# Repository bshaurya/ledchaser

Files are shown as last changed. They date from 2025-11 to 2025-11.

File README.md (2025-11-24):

# shauryachaser LED Chaser

a cricket-ball themed LED chaser because why not  
hardware-only, no firmware needed. Powered by a 555 + CD4017  
and mounted inside a shiny 3D-printed cricket ball enclosure

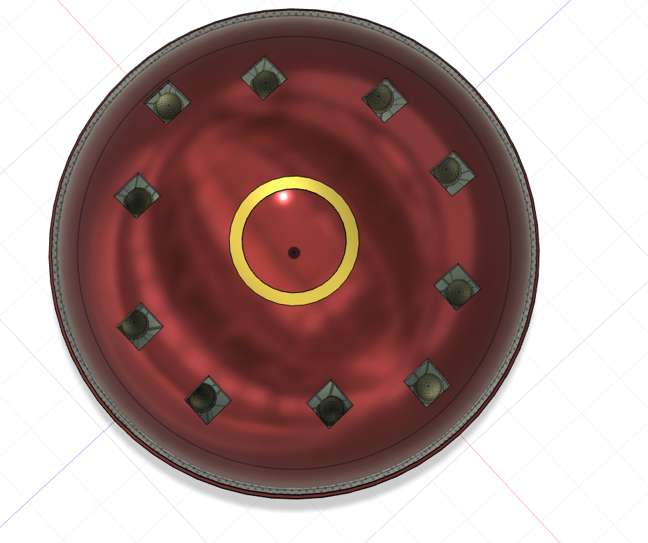
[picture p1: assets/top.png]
Top

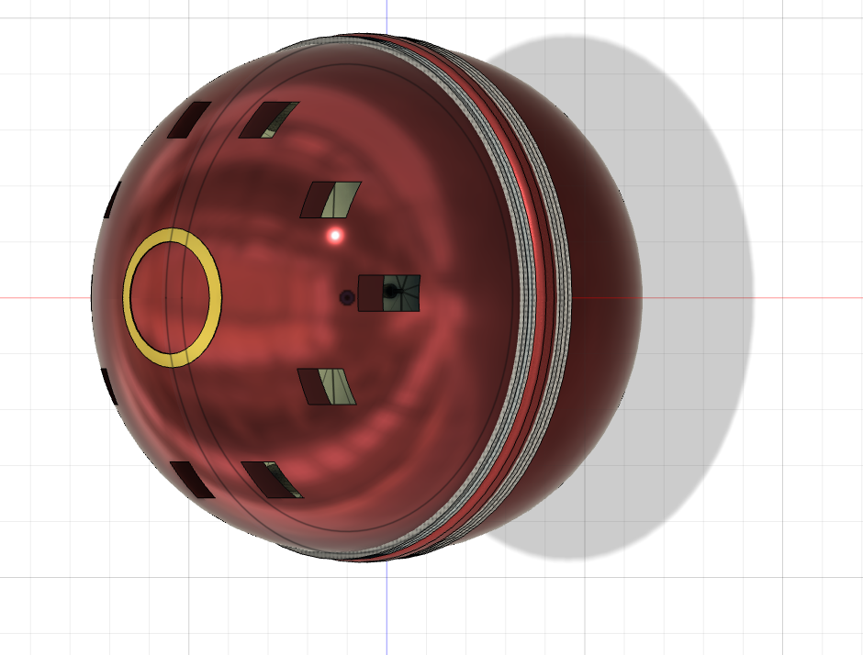
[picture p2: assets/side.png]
Side

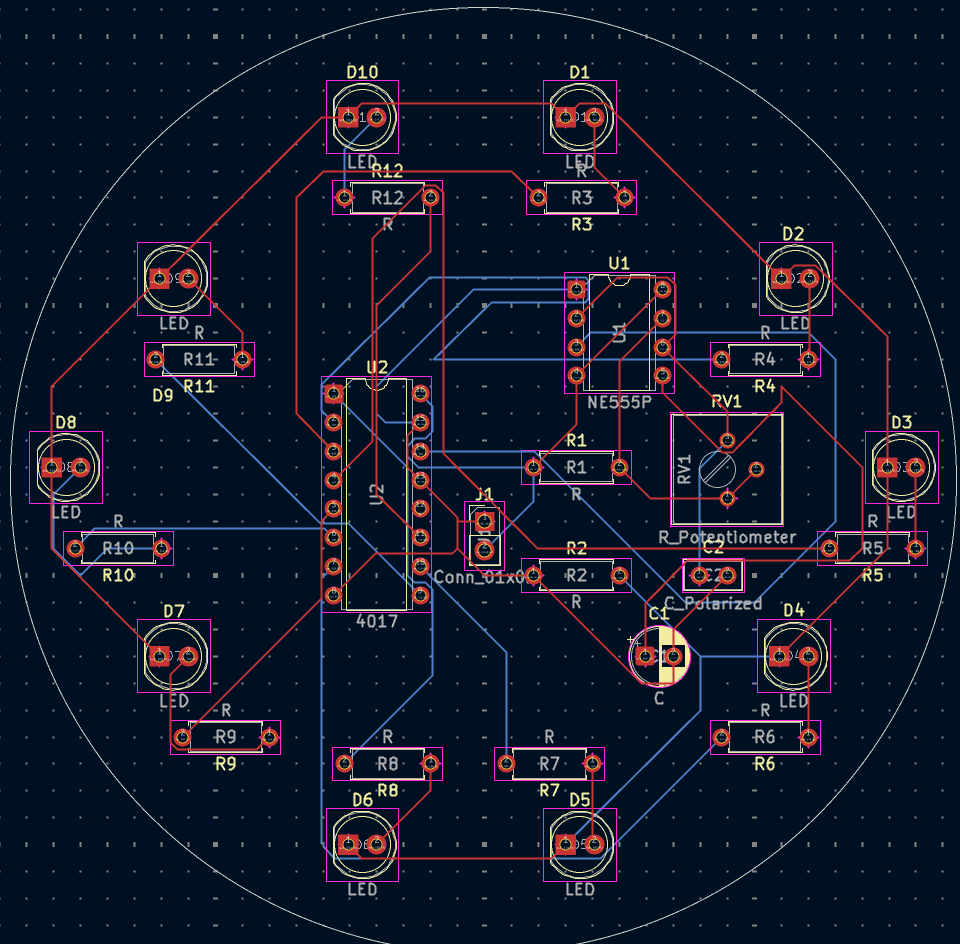
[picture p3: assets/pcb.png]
PCB

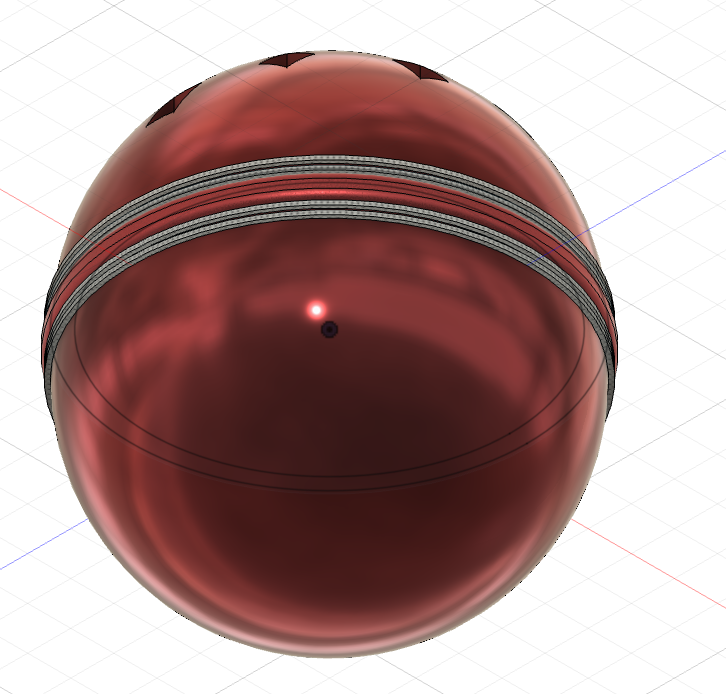
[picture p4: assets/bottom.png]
Bottom

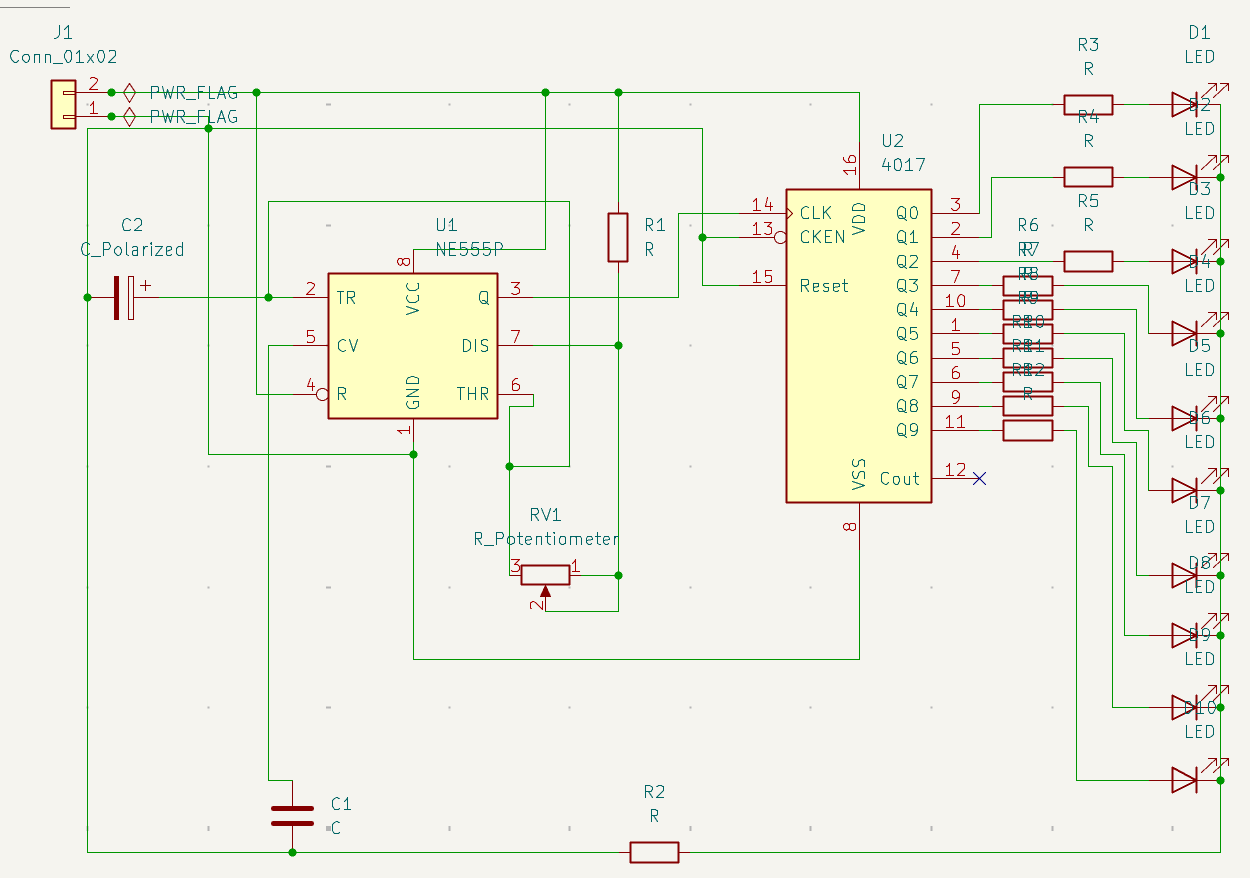
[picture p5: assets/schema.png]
Schematic


## What is this

Basically I wanted to make something fun, weird, and actually functional.  
So I built an LED chaser circuit (classic 555 + CD4017) and wrapped it inside  
a custom Fusion 360 modeled cricket ball enclosure with seam lines, stitching, and a full LED ring.

## Hardware

- **Logic**: NE555P (clock) + CD4017BE (decade counter)
- **LEDs**: 10x 5mm diffused LEDs arranged around the ball
- **Resistors**: 10x LED current limiters + timing resistors
- **Potentiometer**: 50k trim pot for speed control
- **Caps**: 1uF electrolytic + 0.01uF ceramic
- **Power**: Standard 5V input (2-pin header)
- **Enclosure**: 93mm diameter 3D-printed cricket ball with stitched seam

## How it works

- The **555 timer** generates a square wave clock (rate set by RV1).
- Every clock pulse goes into the **CD4017**, which advances to the next output: Q0 → Q1 → Q2 → ... → Q9 → loops back
- Each Q output drives an LED through a 470Ω resistor.
- Result = lights chase around the seam like a rotating/bouncing cricket ball.

You rotate RV1 to speed up or slow down the chase.

## BOM

**ICs**
- 1x NE555P (DIP-8)
- 1x CD4017BE (DIP-16)

**LEDs**
- 10x 5mm LEDs (any color)

**Resistors**
- 10x 470Ω (LEDs)
- 2x 1kΩ (timing)

**Potentiometer**
- 1x 50kΩ trim pot (3386P style)

**Capacitors**
- 1x 1uF electrolytic
- 1x 0.01uF ceramic

**Connectors**
- 1x 2-pin 2.54mm power header

**PCB**
- 1x Circular 93mm custom PCB (KiCad)

**Case**
- ~70–100g PLA (for the cricket ball halves)
- 4x M3x16 screws (optional if mounting)
- 4x M3 heatset inserts (optional)

## Estimated Prices

(approx retail), see BOM.csv

- LEDs: ~$1.00 for all 10  
- Resistors: ~$0.60  
- NE555P: ~$0.40  
- CD4017BE: ~$0.70  
- Potentiometer: ~$0.50  
- Capacitors: ~$0.25  
- Header: ~$0.10  
- PCB: ~$15 (JLCPCB)  
- PLA: ~$1 worth  
**Total:** ~**$20** all-in

## Building one

- `/ledcha` — KiCad PCB + schematic
- `/cad` — 3D Fusion 360 files for the cricket enclosure
- `/assets` — top/side/bottom views, schema and pcb
Steps:

1. Export Gerbers → order PCB from JLCPCB/Seeed/etc.
2. 3D print the cricket ball halves.
3. Solder the PCB: ICs, resistors, LEDs, pot, caps.
4. Insert the PCB inside the enclosure.
5. Power with 5V.
6. Rotate the pot to change chase speed.

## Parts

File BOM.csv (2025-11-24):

Designator | Quantity | Value | Description | Package | Estimated Unit Price (USD) | Estimated Total Price (USD)
U1 | 1 | NE555P | 555 Timer DIP-8 | DIP-8_W7.62mm | 0.40 | 0.40
U2 | 1 | CD4017BE | Decade Counter DIP-16 | DIP-16_W7.62mm | 0.70 | 0.70
R1 | 1 | 1kΩ | Resistor 1kΩ | Axial 7.62mm | 0.05 | 0.05
R2 | 1 | 1kΩ | Resistor 1kΩ | Axial 7.62mm | 0.05 | 0.05
R3 | 1 | 470Ω | LED Series Resistor | Axial 7.62mm | 0.05 | 0.05
R4 | 1 | 470Ω | LED Series Resistor | Axial 7.62mm | 0.05 | 0.05
R5 | 1 | 470Ω | LED Series Resistor | Axial 7.62mm | 0.05 | 0.05
R6 | 1 | 470Ω | LED Series Resistor | Axial 7.62mm | 0.05 | 0.05
R7 | 1 | 470Ω | LED Series Resistor | Axial 7.62mm | 0.05 | 0.05
R8 | 1 | 470Ω | LED Series Resistor | Axial 7.62mm | 0.05 | 0.05
R9 | 1 | 470Ω | LED Series Resistor | Axial 7.62mm | 0.05 | 0.05
R10 | 1 | 470Ω | LED Series Resistor | Axial 7.62mm | 0.05 | 0.05
R11 | 1 | 470Ω | LED Series Resistor | Axial 7.62mm | 0.05 | 0.05
R12 | 1 | 470Ω | LED Series Resistor | Axial 7.62mm | 0.05 | 0.05
RV1 | 1 | 50kΩ Potentiometer | Adjustable Potentiometer | 3386P Vertical | 0.50 | 0.50
C1 | 1 | 0.01uF | Non-Polarized Ceramic Capacitor | Disc 5mm | 0.10 | 0.10
C2 | 1 | 1uF | Electrolytic Capacitor | Radial 5mm | 0.15 | 0.15
D1 | 1 | LED | Standard 5mm LED | LED_D5.0mm | 0.10 | 0.10
D2 | 1 | LED | Standard 5mm LED | LED_D5.0mm | 0.10 | 0.10
D3 | 1 | LED | Standard 5mm LED | LED_D5.0mm | 0.10 | 0.10
D4 | 1 | LED | Standard 5mm LED | LED_D5.0mm | 0.10 | 0.10
D5 | 1 | LED | Standard 5mm LED | LED_D5.0mm | 0.10 | 0.10
D6 | 1 | LED | Standard 5mm LED | LED_D5.0mm | 0.10 | 0.10
D7 | 1 | LED | Standard 5mm LED | LED_D5.0mm | 0.10 | 0.10
D8 | 1 | LED | Standard 5mm LED | LED_D5.0mm | 0.10 | 0.10
D9 | 1 | LED | Standard 5mm LED | LED_D5.0mm | 0.10 | 0.10
D10 | 1 | LED | Standard 5mm LED | LED_D5.0mm | 0.10 | 0.10
J1 | 1 | 2-pin Header | Power Connector | PinHeader_1x02_P2.54mm | 0.10 | 0.10
PCB | 1 | 93mm Diameter Round PCB | Custom Board | N/A | 15.98 | 15.98
TOTAL
TOTAL_COMPONENT_COST |  |  |  |  |  | 3.65
TOTAL_WITH_PCB |  |  |  |  |  | 19.63

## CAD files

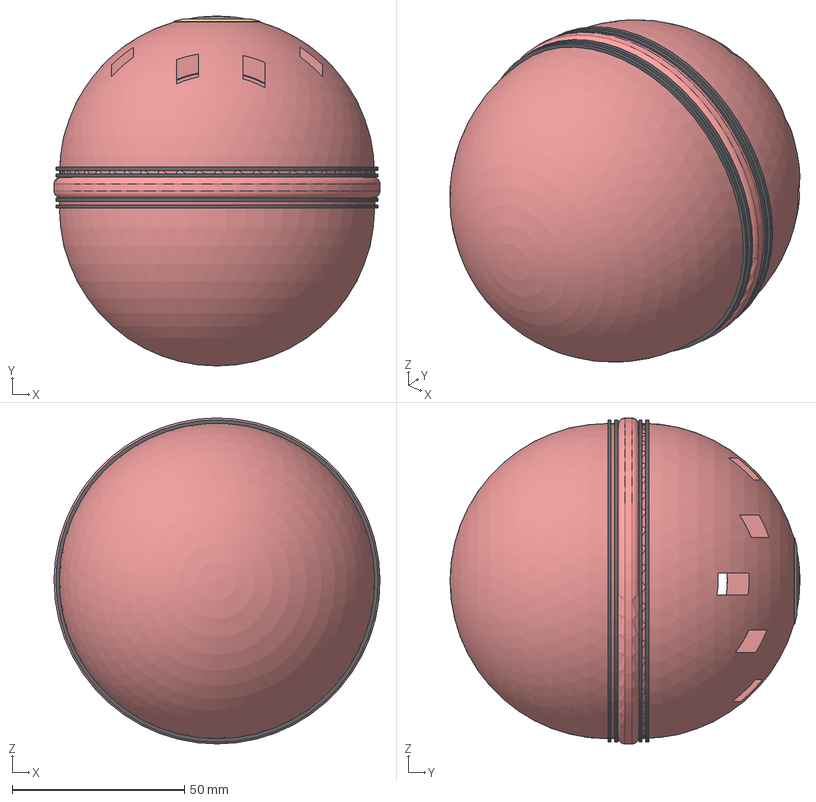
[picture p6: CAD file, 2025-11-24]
cad/ledchaser.step
94.6 x 101.6 x 94.6 mm

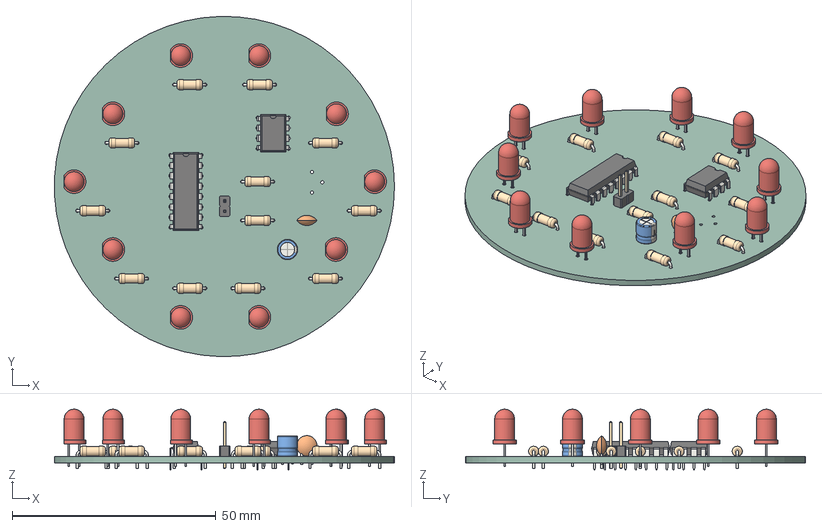
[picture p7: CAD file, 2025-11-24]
ledcha/ledcha.step
83.5 x 83.5 x 14.9 mm
R_Axial_DIN0207_L6.3mm_D2.5mm_P7.62mm_Horizontal x 12
LED_D5.0mm x 10
DIP-8_W7.62mm
C_Disc_D5.0mm_W2.5mm_P2.50mm
DIP-16_W7.62mm
PinHeader_1x02_P2.54mm_Vertical
CP_Radial_D5.0mm_P2.50mm
ledcha_PCB

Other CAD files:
cad/bottom.f3d
cad/ledchaser.f3z
cad/top.f3d

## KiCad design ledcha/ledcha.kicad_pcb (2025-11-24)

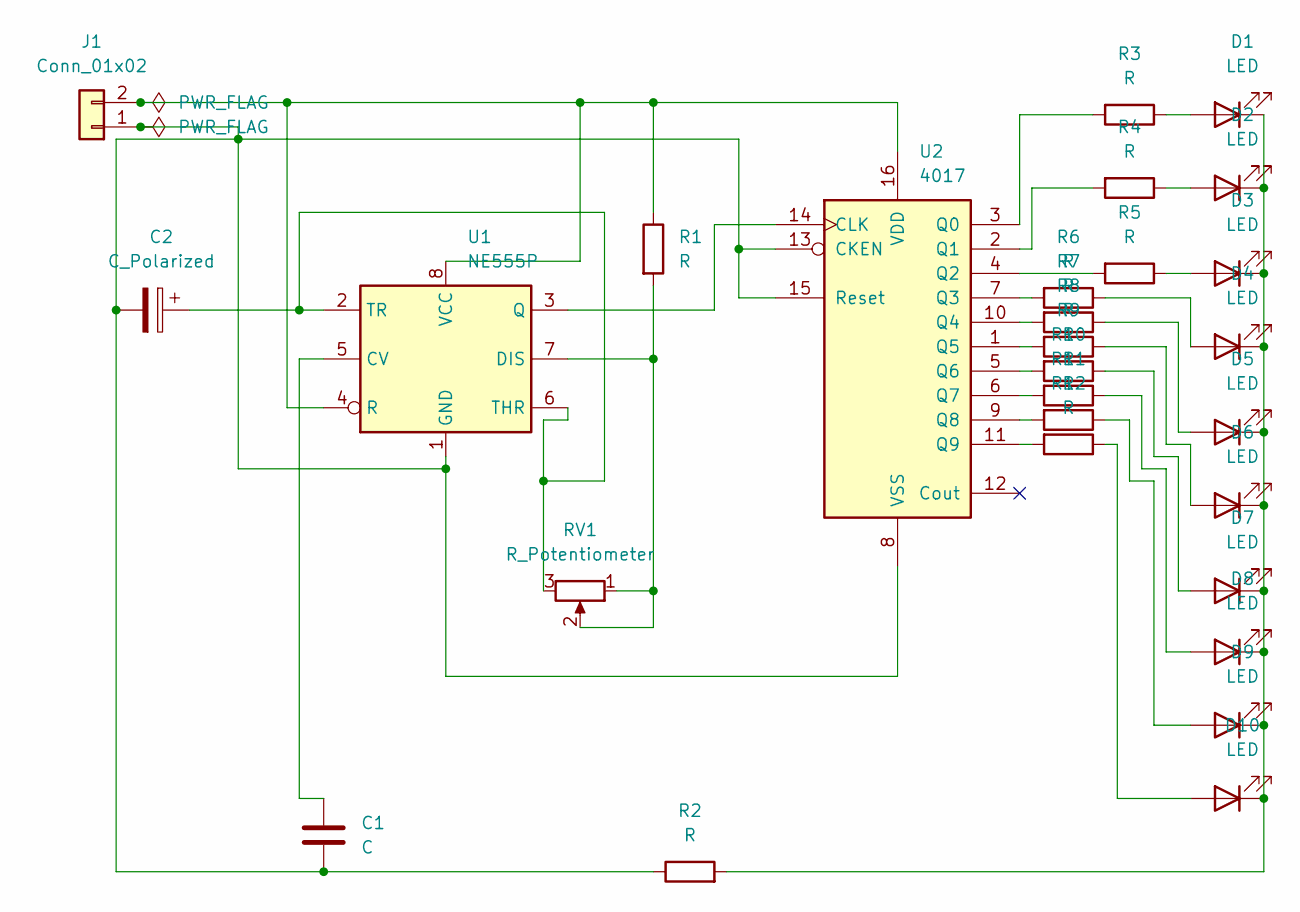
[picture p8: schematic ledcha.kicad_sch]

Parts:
C1: C; CP_Radial_D5.0mm_P2.50mm
C2: C_Polarized; C_Disc_D5.0mm_W2.5mm_P2.50mm
D1, D2, D3, D4, D5, D6, D7, D8, D9, D10: LED; LED_D5.0mm
J1: Conn_01x02; PinHeader_1x02_P2.54mm_Vertical
R1, R2, R3, R4, R5, R6, R7, R8, R9, R10, R11, R12: R; R_Axial_DIN0207_L6.3mm_D2.5mm_P7.62mm_Horizontal
RV1: R_Potentiometer; Potentiometer_Bourns_3386P_Vertical
U1: NE555P; DIP-8_W7.62mm
U2: 4017; DIP-16_W7.62mm

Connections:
unnamed: D1.2 (A), R3.1
unnamed: D1.1 (K), D2.1 (K), D3.1 (K), D4.1 (K), D5.1 (K), D6.1 (K), D7.1 (K), D8.1 (K), D9.1 (K), D10.1 (K), R2.2
unnamed: D2.2 (A), R4.1
unnamed: D3.2 (A), R5.1
unnamed: D4.2 (A), R6.1
unnamed: D5.2 (A), R7.1
unnamed: D6.2 (A), R8.1
unnamed: D7.2 (A), R9.1
unnamed: D8.2 (A), R10.1
unnamed: D9.2 (A), R11.1
unnamed: D10.2 (A), R12.1
unnamed: C1.2, C2.2, J1.1, R2.1, U1.1 (GND), U2.8 (VSS), U2.13 (CKEN), U2.15 (Reset)
unnamed: J1.2, R1.1, U1.4 (R), U1.8 (VCC), U2.16 (VDD)
unnamed: C1.1, U1.5 (CV)
unnamed: R1.2, RV1.1, RV1.2, U1.7 (DIS)
unnamed: U1.3 (Q), U2.14 (CLK)
unnamed: C2.1, RV1.3, U1.2 (TR), U1.6 (THR)
unnamed: R3.2, U2.3 (Q0)
unnamed: R4.2, U2.2 (Q1)
unnamed: R5.2, U2.4 (Q2)
unnamed: R6.2, U2.7 (Q3)
unnamed: R7.2, U2.10 (Q4)
unnamed: R8.2, U2.1 (Q5)
unnamed: R9.2, U2.5 (Q6)
unnamed: R10.2, U2.6 (Q7)
unnamed: R11.2, U2.9 (Q8)
unnamed: R12.2, U2.11 (Q9)

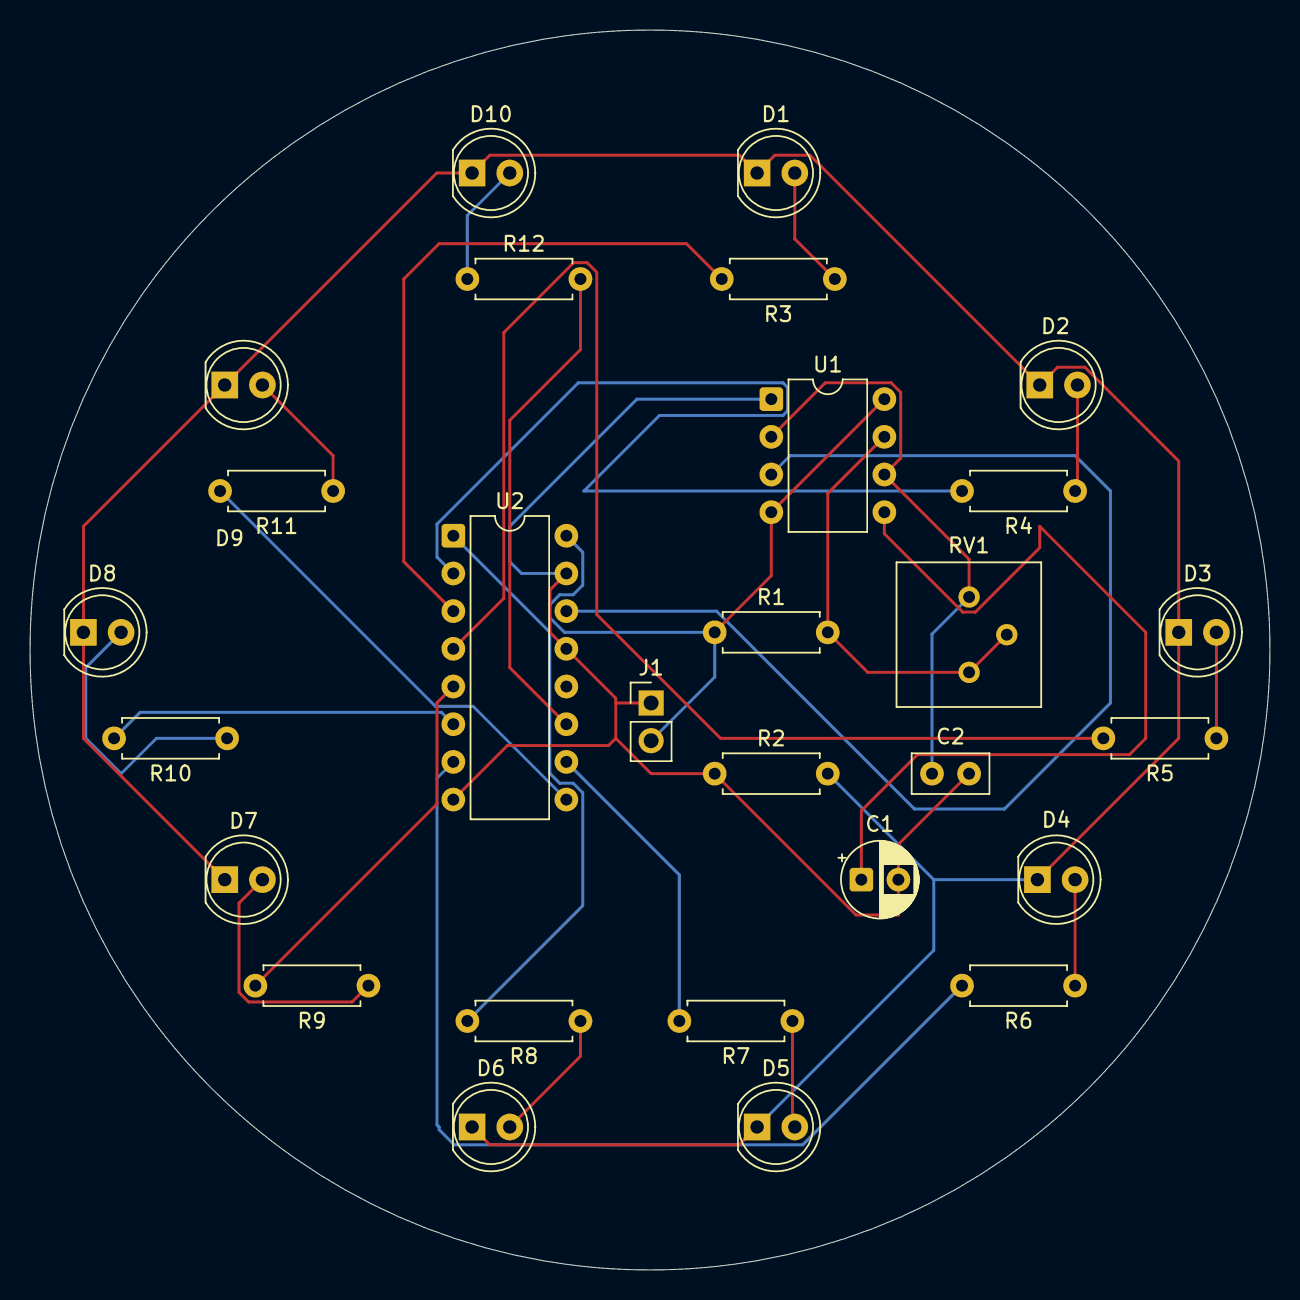
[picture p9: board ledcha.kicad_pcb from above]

Board: 2 copper layers, 83.6 x 83.6 mm, 28 parts (0 on the bottom side), 27 nets.

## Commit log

2025-11-24 uploaded all files
    [BOM.csv, bottom.f3d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]
2025-11-24 added .step file for cad
    [ledchaser.step]
2025-11-24 fixed bom
    [BOM.csv]
